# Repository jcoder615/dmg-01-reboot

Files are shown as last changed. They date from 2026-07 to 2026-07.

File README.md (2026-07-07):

# dmg-01-reboot (Cheese Boy)

A fully modernized, retro-futuristic revive for the classic Game Boy DMG-01. This is a complete DIY project featuring a Raspberry Pi Zero, a vibrant full-color LCD screen, and working microSD cartridges—all in the iconic original shell.

---

## 🎮 What Is This?

`dmg-01-reboot` is an open-source hardware and software project that brings the beloved Game Boy into the modern era. It's designed for retro gaming enthusiasts, makers, smart-but-bored people, and anyone who loves a good weekend project.

This is **my first big project**, so I'm excited to share it and would love your feedback, builds, and recommendations!

---

## ✨ Features

- **Raspberry Pi Zero Powered** - Compact, powerful, and perfect for retro emulation
- **Full-Color LCD Screen** - Say goodbye to the monochrome dot matrix
- **Backlight** - For the late-night Goomba-stomping grinds
- **MicroSD Cartridges** - Load your favorite games from cartridge-style media
- **Original DMG-01 Shell** - Classic form factor with modern internals
- **RetroPie Compatible** - Runs RetroPie with custom hardware plugins for seamless integration
- **Fully Open-Source** - All design files and code included in this repository

---

## 🛠️ What You Need to Build

### Skills Required
- Basic soldering experience (through-hole)
- Surface mount soldering (SMT/SMD) experience
- Familiarity with Raspberry Pi setup

### Materials & Bill of Materials

This project consists of multiple PCBs, each with its own Bill of Materials (BOM). Check the relevant BOM file for each PCB you're building:

- **Main Board** - See `/hardware/main-board/BOM.md`
- **Display Board** - See `/hardware/display-board/BOM.md`
- **Cartridge Board** - See `/hardware/power-board/BOM.md`
- *(Add additional boards as your design takes shape)*

**Note:** BOMs are organized by PCB in the `/hardware` directory. Each folder contains:
- Schematic files
- PCB design files (Gerber format for ordering)
- Component BOM for that specific board

---

## 📦 Repository Structure

```
dmg-01-reboot/
├── hardware/           # PCB design files, schematics, and BOMs
│   ├── main-board/     # [Add your PCB folders here]
│   ├── display-board/
│   ├── power-board/
│   └── ...
├── software/           # RetroPie plugins and configuration
├── docs/              # Build guides and troubleshooting
├── assets/            # Images and diagrams
└── README.md          # This file
```

---

## 🚀 Quick Start

1. **Order PCBs** - Use the design files in `/hardware` to order from your favorite PCB manufacturer (Gerber files included)
2. **Gather Components** - Consult the BOM files and DigiKey for all required parts
3. **Solder the Board** - Assemble through-hole, SMT, and SMD components
4. **Set Up Raspberry Pi** - Flash RetroPie and install the custom hardware plugins from `/software`
5. **Assemble** - Fit everything into the Game Boy shell
6. **Load Games** - Add your favorite ROMs to the microSD cartridge
7. **Enjoy!** - Play retro games on modern hardware

For detailed build instructions, see `/docs/BUILD_GUIDE.md`.

---

## 💻 Software

The project runs **RetroPie** with custom control routing designed specifically for the dmg-01-reboot hardware. These plugins handle:
- LCD display integration
- Button mapping and input handling
- MicroSD cartridge detection and ROM loading

Installation and configuration instructions are included in this repo.

**small disclaimer**: this is not a package install. it will just be a guide for mapping with the retropie software. In fact, this is my first time using RetroPie or even doing DIY game mods apart from programming school calculators, so please give me some grace.  

---

## 📸 Share Your Build!

This is an open-source community project, and **I'd love to hear from you!** If you build one, please reach out:

📧 **Email me photos and recommendations** - Your feedback helps improve the design and helps other builders learn from real-world builds.

Whether it's a tip, a modification, a bug fix, or just pictures of your finished device—**all contributions are welcome and encouraged**. This is my first big project, so your input is invaluable.

---

## 🤝 Contributing

We welcome contributions! Here's how:

1. **Fork the repository**
2. **Make your changes** (hardware improvements, bug fixes, software enhancements)
3. **Test thoroughly**
4. **Submit a pull request** with a description of your changes
5. **Email me too!** - Include pictures or notes about what you changed

---

## 📋 Project Status

🚧 **In Active Development** - The design is still being refined. Check back for updates as the project matures.

Once the design is fully finalized, a detailed changelog and version history will be added.

---

## Troubleshooting

Having issues? Check `/docs/TROUBLESHOOTING.md` for common problems and solutions. If you find something not covered, please reach out!

---

## ⚠️ Disclaimer

This is a personal/hobby project built for educational and hobbyist purposes. Make sure you own the games/ROMs you're playing. Respect copyright laws in your jurisdiction.
I am not an electronics expert. I consider my self well-versed in electronics. keep in mind that I WAS BORN IN 2013; although I have worked with and taught myself the art of electronics since around 2018. I AM NOT, IN ANY WAY, RESPONSIBLE FOR ANY PHYSICHAL OR MENTAL HARM CAUSED BY MY PROJECT. YOU CHOSE TO BULD THE PROJECT. I AM JUST THE DESIGNER.

---

## 📄 License

This project is open-source. See the `LICENSE` file for details.

---

## Acknowledgments

Thanks to:
* Texas Instruments Datasheets (`https://www.ti.com/lit/ds/symlink/tps56339.pdf?ts=1783426660975`),
* Kamicane's super-dmg-01 repo for some motherboard footprints (`https://github.com/kamicane/Super-DMG-01`),
* The Raspberry Pi foundation, for providing the core of this project,
* And the Ezell-Turner Family for inspiration, encouragement, and an absolutely stunning Independence Day fireworks show!

  This project builds on your shoulders.

  I strongly encourage you to check out Vadis Turner's Mixed media art sculptures and support her work. Her site is at `https://vadisturner.com`. Your assistance in growing her community would mean a lot to me!
Thank you Clay Ezell for donating your childhood DMG-01, and my parents, who have been here for me to help me get through the hardest parts of my life.
What a long, strange trip it's been!

---

## 📧 Contact

Have questions, suggestions, or just want to share your build? **Reach out!**

Feel free to open an issue on GitHub or send me an email with your thoughts. This is a community project, and your feedback makes it better.

---

**Happy building, and enjoy your modernized Game Boy!**

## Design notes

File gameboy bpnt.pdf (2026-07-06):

📐 SECTION 1: MASTER PCB DIMENSIONS & RADIUS FILE

PCB System Module [1, (https://www.wevolver.com/article/pcbs-thickness-understanding-thickness-variations) 2, (https://www.pcbway.com/project/shareproject/Replacement_PCB_for_the_original_gameboy_DMG_with_1_watt_speaker_lipo_battery_a_745f43ad.html) 3] (https://www.pcbway.com/project/shareproject/Game_Boy_DMG_Color_DMGC_CPU_01_2f5c743d.html) | Outer Dimensio ns (W x H) | Curve Corner Radii | Required Thicknes s
Front Controller Board | 78.0 mm x 57.0 mm | Top Corners: R2.5mm Bottom Corners: R12.0mm | 1.2 mm (For crisp membran e travel)
Back Motherboa rd | 83.5 mm x 75.0 mm | Left & Right Top: R4.0mm Bottom Trim: R1.5mm | 1.6 mm (Standard rigid structural build)
Cartridge Board (Internal) | 53.5 mm x 60.0 mm | Top Left/Right: R3.0mm Notch Step-downs: R1.0mm | 1.2 mm (Prevents jamming in physical slot)
Audio Out Sub-Board | 31.0 mm x 11.5 mm | Square Profile: 0mm (Straight V-Score) | 1.6 mm (Standard rigid build)

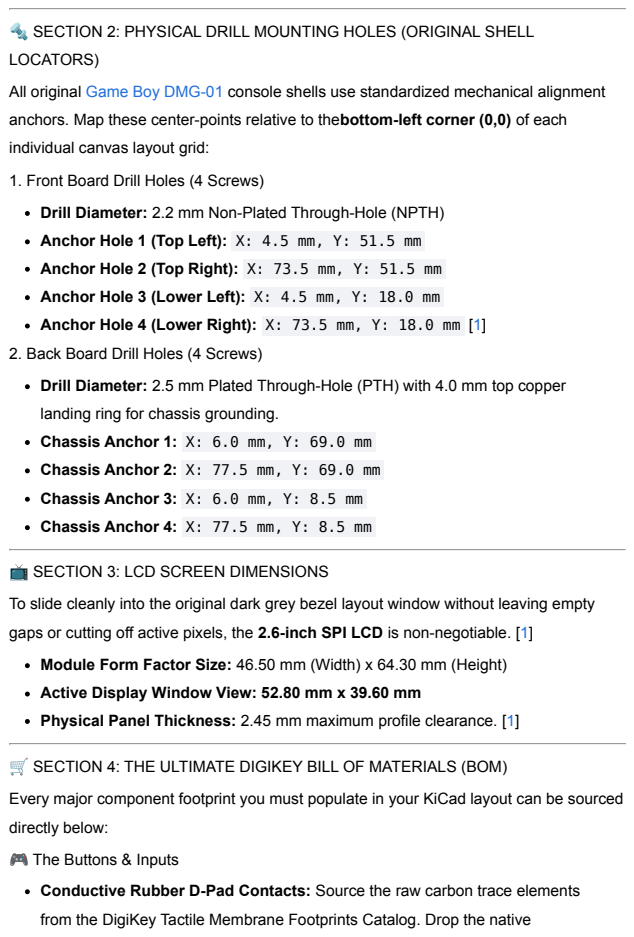
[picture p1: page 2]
Anchor Hole 1 (Top Left):; Anchor Hole 2 (Top Right):; Anchor Hole 3 (Lower Left):; Anchor Hole 4 (Lower Right):; Chassis Anchor 1:; Chassis Anchor 2:; Chassis Anchor 3:; Chassis Anchor 4:

🔩 SECTION 2: PHYSICAL DRILL MOUNTING HOLES (ORIGINAL SHELL
LOCATORS)
All original Game Boy DMG-01 (https://www.google.com/search?ibp=oshop&q=product) console shells use standardized mechanical alignment
anchors. Map these center-points relative to thebottom-left corner (0,0) of each
individual canvas layout grid:
1. Front Board Drill Holes (4 Screws)
Drill Diameter: 2.2 mm Non-Plated Through-Hole (NPTH)
2. Back Board Drill Holes (4 Screws)
Drill Diameter: 2.5 mm Plated Through-Hole (PTH) with 4.0 mm top copper
landing ring for chassis grounding.

📺 SECTION 3: LCD SCREEN DIMENSIONS
To slide cleanly into the original dark grey bezel layout window without leaving empty
gaps or cutting off active pixels, the 2.6-inch SPI LCD is non-negotiable. [1] (https://www.dimensions.com/element/game-boy)
Module Form Factor Size: 46.50 mm (Width) x 64.30 mm (Height)
Active Display Window View: 52.80 mm x 39.60 mm
Physical Panel Thickness: 2.45 mm maximum profile clearance. [1] (https://www.dimensions.com/element/game-boy)

🛒 SECTION 4: THE ULTIMATE DIGIKEY BILL OF MATERIALS (BOM)
Every major component footprint you must populate in your KiCad layout can be sourced
directly below:
🎮 The Buttons & Inputs
Conductive Rubber D-Pad Contacts: Source the raw carbon trace elements
from the DigiKey Tactile Membrane Footprints Catalog. Drop the native

Conductive_Rubber_Pad_DMG footprint pattern across your copper layout layers.
X/Y SMT Tactile Switches (Extra Controls): Purchase the low-profile Omron Electronics B3F Series Tactile Switches. (https://www.google.com/search?ibp=oshop&q=product) They require standard 6.0 mm x 6.0 mm square layouts.

The SMT MicroSD Cartridge Slot (With Solder Paste Terminals): Buy the high-retention GCT MEM2075-00-140-01-A Push-Push Socket. (https://www.google.com/search?ibp=oshop&q=product) It has rugged physical through-hole metal chassis grounding anchor posts to absorb insertion forces. [1, (https://www.digikey.com/en/product-highlight/g/gct/usb-type-c) 2] (https://www.digikey.com/en/products/filter/barrel-connectors/audio-connectors/434)
The "Smtn" Extension Connector (Modern USB Upgrade): To fully replace Nintendo's old, proprietary EXT Link Port, use the GlobTek JACK-USBC-24SMT-THSS Right-Angle Connector. This fits perfectly flush inside the classic shell cutout window. [1] (https://www.digikey.com/en/products/filter/barrel-connectors/audio-connectors/434)
The Audio Out Sub-Board Headphone Jack: Source the Kycon STX-3120-5B Right-Angle 3.5mm Stereo Jack. (https://www.google.com/search?ibp=oshop&q=product) It features the necessary internal un-mating physical structural leaf-switch pins to automatically mute your main internal chassis speaker whenever you plug in standard headphones. [1] (https://www.digikey.com/en/products/filter/barrel-connectors/audio-connectors/434)

The Rule: If you snack on cheese crackers or real cheddar at your soldering bench, grease and cheese crumbs act as high-impedance dielectric barriers.

🔌 Power, Audio, & Storage

🧀 SECTION 5: CRITICAL ASYMMETRIC CHEESE CLEARANCE INDEX [1] (https://www.digikey.com/en/pcb-builder/)

Since you explicitly requested cheese, you must account for Thermal Swiss Clearance during your physical trace-routing pass.

text

____________________________________
( | 🧀 [PAD] | o (3.3V) | [PAD] )
( O (GND) | .---. | o (MOSI) | )
( | / | \ | _ | )
( | | MISO | ( ) [CHEESE] )
\_________\_____/________________/

Use code with caution.

The Safe Keepout Fix: Keep a 3.0 mm Keep-Out Zone Mask around your
high-speed SPI clock lines ( SCLK | and | MOSI ). Any stray physical cheese dust
bridging your 1.1 mm MicroSD socket pins will cause immediate storage boot loops and corrupt your emulation save files! Keep the workbench completely squeegee-clean.

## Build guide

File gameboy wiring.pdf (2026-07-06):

️ DMG-01 GAME BOY ZERO: MASTER WIRING BLUEPRINT

SECTION 1: Front Isolated Button Board Layout

All button contact pads utilize a Common Ground configuration. Wire one side of every conductive pad to a shared Ground plane (GND). Trace the isolated data pad of each button directly to the designated Raspberry Pi GPIO pin below.

Game Boy Button Pad | Target Pi Zero 2 W GPIO Pin | Physical Pi Header Pin
D-Pad UP | GPIO 12 | Pin 32
D-Pad DOWN | GPIO 13 | Pin 33
D-Pad LEFT | GPIO 16 | Pin 36
D-Pad RIGHT | GPIO 19 | Pin 35
Action Button A | GPIO 26 | Pin 37
Action Button B | GPIO 20 | Pin 38
Action Button X | GPIO 21 | Pin 40
Action Button Y | GPIO 6 | Pin 31
SELECT | GPIO 5 | Pin 29

START | GPIO 0 | Pin 27
COMMON GROUND | GND | Pin 30 (or any Pi GND pin)

SECTION 2: 2.6" ST7789 SPI Display Pin Mapping

The 2.6-inch 240x320 SPI screen connects via a surface-mount FPC ribbon slot connector footprint on your PCB canvas. Ensure your software configures the Pi's secondary SPI bus (SPI1) if your main SPI bus is dedicated to the cartridge reader.

Display Ribbon Pin / Signal | Pi Zero 2 W Designati on | Physical Pi Header Pin | Function / Purpose
VCC | 3.3V Power | Pin 17 | Core Logic Power (3.3V Input)
GND | Ground | Pin 25 | Common System Ground
SCL / SCLK | GPIO 21 (SPI1 SCLK) | Pin 40 (Shared) | Master Clock Signal
SDA / MOSI | GPIO 20 (SPI1 MOSI) | Pin 38 (Shared) | Master Out / Data Input

RES / RESET | GPIO 25 | Pin 22 | Hardware Reset Line
DC / RS | GPIO 24 | Pin 18 | Data / Command Selection
CS / CE | GPIO 18 (SPI1 CE0) | Pin 12 | Chip Enable Line
LEDA / BACKLIGH T | 5V Power (via 100Ω Resistor) | Pin 2 | Backlight LED Power Supply

SECTION 3: MicroSD SMT Cartridge Slot Passthrough

The surface-mount MicroSD socket (GCT MEM2075) sits inside the empty cartridge frame shell, routing power and data lines directly through the console's desoldered 32-pin edge jack using the main SPI bus (SPI0).

MicroSD Socket Pin | Signal Name | Target Pi Zero 2 W GPIO Pin | Physical Pi Pin
Pin 1 (DAT2) | NC / Pull-up | Not Connected | —
Pin 2 (CD/DAT3) | CS (Chip Select) | GPIO 8 (SPI0 CE0) | Pin 24

1. Controls Area: Button_Switch_Keyboard:Conductive_Rubber_Pad_DMG (Provides the physical surface contact wheel comb layers for the rubber conductive pads).
2. Extra Buttons: Button_Switch_SMD:SW_SPST_OMRON_B3F-10xx (If opting for physical SMT tactile micro-switches for your hidden rear or front X/Y buttons).
3. Cartridge Profile: GumpyFunction_GameBoy_Cartridge_Template (Maintains physical circuit dimensions matching the console interior casing
Pin 3 (CMD) | MOSI (Data In) | GPIO 10 (SPI0 MOSI) | Pin 19
Pin 4 (VDD) | 3.3V Power | 3.3V Regulated Output | Pin 1
Pin 5 (CLK) | SCK (Clock) | GPIO 11 (SPI0 SCLK) | Pin 23
Pin 6 (VSS) | GND | System Ground | Pin 6
Pin 7 (DAT0) | MISO (Data Out) | GPIO 9 (SPI0 MISO) | Pin 21
Pin 8 (DAT1) | NC / Pull-up | Not Connected | —

SECTION 4: Step-by-Step KiCad & Assembly Workflow

Step 1: Footprint Asset Checklist

Verify that your KiCad workspace has loaded these explicit native and community profiles before tracing:

tracks).
4. Display Interface: | Connector_FFC-FPC:Hirose_FH12-10S-0.5SH | (For
routing the flexible display connector lines).
1. Align the custom Stainless Steel SMD Stencil flat across your unpopulated manufactured PCB panel.
2. Apply a thin, even bead of SMT Solder Paste across the stencil cutouts using a squeegee blade or card.
3. Lift the stencil cleanly away, then gently drop your surface-mount MicroSD socket and FPC jack directly onto the tacky gray paste footprints using fine tweezers.
4. Set your Hot Air Rework Station to 320°C (608°F) with low airflow. Hold the nozzle vertically above the components until you see the paste liquidity turn bright silver and snap onto the copper pads via surface tension.
1. Open the file | /boot/firmware/config.txt | inside your terminal editor.
2. Inject this instruction line to register your target console edge signals as a functional storage module:
text

Use code with caution.
3. Save the configurations and restart the Pi. The operating system will automatically populate and scan directories through your custom Game Boy cartridges exactly like an integrated external hard drive.
Step 2: Solder Paste Stencil Reflow

Because hand-soldering the 1.1mm gaps on the GCT MEM2075 or the 0.5mm FPC slots is highly prone to bridging terminals, execute a paste reflow:

Step 3: Software Configurations

To configure Raspberry Pi OS or RetroPie to automatically mount your custom hardware slot insertions at boot, map an overlay drive array within the system:

dtoverlay=spi-sdcard,overclock_50=1
